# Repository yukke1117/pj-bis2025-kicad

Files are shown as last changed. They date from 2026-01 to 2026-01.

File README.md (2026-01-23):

# af-pj-bis2025

精密アナログ信号処理・データ取得回路のKiCadプロジェクト

## 概要

本プロジェクトは、高精度アナログ信号の取得・調整を目的とした回路基板設計です。24ビットADCを中心に、低ノイズ電源回路とオペアンプによる信号調整回路を組み合わせています。STM32マイコンとの接続を想定した拡張基板として設計されています。

## 主要スペック

- **ADC**: ADS1220IPW (24-bit, TI)
- **オペアンプ**: OPA2380AIDGKR (デュアル), THS4552IPWR (全差動)
- **電圧リファレンス**: REF5050IDR (5V), ADR130BUJZ-REEL7 (精密)
- **電源IC**: MIC5237-5.0YT (5V LDO), UA78L06ACPK (6Vリニアレギュレータ)
- **MOSFET**: ALD114904APAL (低閾値)
- **精密アンプ**: LT1991ACMS-TRPBF
- **コネクタ**: FH28-10S-0.5SH (FPC), SMAコネクタ x2, CN7/CN10 (STM32 Nucleo互換)

## ディレクトリ構成

```
pj-bis2025-kicad/
├── af-pj-bis2025.kicad_pro      # プロジェクトファイル
├── af-pj-bis2025.kicad_sch      # 回路図
├── af-pj-bis2025.kicad_pcb      # PCBレイアウト
├── af-pj-bis2025.kicad_prl      # プロジェクトローカル設定
├── af-pj-bis2025.csv            # 部品表 (BOM)
├── af-pj-bis2025.glb            # 3Dモデル (GLB形式)
├── freerouting.dsn              # 自動配線用ファイル
├── af-pj-bis2025-backups/       # バックアップファイル
├── pj-bis2025.pretty/           # カスタムフットプリントライブラリ
├── pj-bis2025.kicad_sym         # カスタムシンボルライブラリ
├── ultralibrary_zip/            # コンポーネントライブラリ (Ultra Librarian)
├── step/                        # 3Dモデルファイル (STEP形式)
├── stm32/                       # STM32関連サブプロジェクト
│   ├── stm32.kicad_sch          # STM32回路図
│   └── stm32.kicad_pcb          # STM32 PCBレイアウト
├── production/                  # JLCPCB製造用ファイル
│   ├── af-pj-bis2025.zip        # ガーバーファイル一式
│   ├── bom.csv                  # 部品表
│   ├── positions.csv            # 実装位置データ
│   └── netlist.ipc              # IPCネットリスト
└── jlcpcb/                      # JLCPCB製造設定
```

## カスタムライブラリ

### pj-bis2025.pretty (フットプリント)

| フットプリント | 説明 |
|---|---|
| ADS1220-PW16-M | ADC (TSSOP-16) |
| OPA2380-DGK8-M | デュアルオペアンプ (VSSOP-8) |
| THS4552-PW0016A_M | 全差動アンプ (TSSOP-16) |
| REF5050-D8-M | 電圧リファレンス (SOIC-8) |
| LT1991-MSOP-10_MS_LIT-M | 精密アンプ (MSOP-10) |
| MIC5237_5_0YT | 5V LDO (SOT-223) |
| UA78L06ACPK-PK0003A_M | 6Vレギュレータ (SOT-89) |
| ADR130BUJZ_REEL7 | 精密電圧リファレンス (SOT-23) |
| ALD114904APAL-8-PDIP_ALD | MOSFET (PDIP-8) |
| HIROSE_FH28-10S-0.5SH_05_ | FPCコネクタ |
| PTS_647_SN50_SMTR2_LFS | プッシュボタンスイッチ |

### ultralibrary_zip (Ultra Librarian)

Ultra Librarianからダウンロードしたコンポーネントライブラリを含みます。

## 必要環境

- **KiCad 9.0** 以上

## 設計ルール

| 項目 | 値 |
|---|-----|
| 最小トラック幅 | 0.25mm |
| 最小クリアランス | 0.2mm |
| ビア径 | 0.6mm |
| ビアドリル | 0.3mm |
| 最小ホールクリアランス | 0.28mm |
| エッジクリアランス | 0.5mm |

## 製造

製造ファイルは `production/` ディレクトリに出力済みです。JLCPCB向けの以下のファイルが含まれています:

- `af-pj-bis2025.zip` - ガーバーファイル一式
- `bom.csv` - 部品表 (SMT実装用)
- `positions.csv` - 部品配置データ (SMT実装用)

## ライセンス

senserity

## 更新履歴

- 2025-01-23: 基板完成、DRCエラーフリー
- 2025-01-20: GNDベタ配置、アナログ配線完了
- 2025-01-19: アノテーション再定義、フットプリント更新
- 2025-01-18: PCBレイアウト変更
- 2024-11-24: 初期設計

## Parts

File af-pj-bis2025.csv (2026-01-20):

Reference | Qty | Value | DNP | Exclude from BOM | Exclude from Board | Footprint | Datasheet
C1,C2,C12,C16,C20,C23,C27,C30,C34,C35,C36 | 11 | 0.1u_pass |  |  |  | Capacitor_SMD:C_0805_2012Metric_Pad1.18x1.45mm_HandSolder | ~
C3 | 1 | 22u |  |  |  | Capacitor_Tantalum_SMD:CP_EIA-3528-15_AVX-H_HandSolder | ~
C4,C33 | 2 | 1u |  |  |  | Capacitor_SMD:C_0805_2012Metric_Pad1.18x1.45mm_HandSolder | ~
C5 | 1 | TAJR105K016RNJ |  |  |  | Capacitor_SMD:C_0805_2012Metric_Pad1.18x1.45mm_HandSolder | TAJR105K016RNJ
C6,C7 | 2 | 0.1u |  |  |  | Capacitor_SMD:C_0805_2012Metric_Pad1.18x1.45mm_HandSolder | ~
C8,C9 | 2 | 4.7n |  |  |  | Capacitor_SMD:C_0805_2012Metric_Pad1.18x1.45mm_HandSolder | ~
C10,C11,C13,C14 | 4 | 47n |  |  |  | Capacitor_SMD:C_0805_2012Metric_Pad1.18x1.45mm_HandSolder | ~
C15,C21,C22,C28 | 4 | 270p |  |  |  | Capacitor_SMD:C_0805_2012Metric_Pad1.18x1.45mm_HandSolder | ~
C17,C24 | 2 | 470p |  |  |  | Capacitor_SMD:C_0805_2012Metric_Pad1.18x1.45mm_HandSolder | ~
C18,C25 | 2 | 1n |  |  |  | Capacitor_SMD:C_0805_2012Metric_Pad1.18x1.45mm_HandSolder | ~
C19,C26 | 2 | 22n |  |  |  | Capacitor_SMD:C_0805_2012Metric_Pad1.18x1.45mm_HandSolder | ~
C29 | 1 | 0.33u |  |  |  | Capacitor_SMD:C_0805_2012Metric_Pad1.18x1.45mm_HandSolder | ~
C31 | 1 | T491A685K020AT |  |  |  | pj-bis2025:Vref_in_tantal_T491A685K020AT_CAPMP3.4X1.6_1.8N_KEM-M | https://content.kemet.com/datasheets/KEM_T2005_T491.pdf
C32 | 1 | 293D336X9016C2TE3 |  |  |  | pj-bis2025:Vref_out_tantal_293D336X9016C2TE3_CAP_293D-C_VSS | https://www.vishay.com/doc?40002
D1 | 1 | LED |  |  |  | LED_SMD:LED_0805_2012Metric_Pad1.15x1.40mm_HandSolder | ~
J1 | 1 | CN7 |  |  |  | Connector_PinSocket_2.54mm:PinSocket_2x19_P2.54mm_Vertical | ~
J2 | 1 | CN10 |  |  |  | Connector_PinSocket_2.54mm:PinSocket_2x19_P2.54mm_Vertical | ~
J3 | 1 | FH28-10S-0.5SH_05_ |  |  |  | pj-bis2025:HIROSE_FH28-10S-0.5SH_05_
J4 | 1 | Conn_02x05_Odd_Even |  |  |  | Connector_PinSocket_2.54mm:PinSocket_2x05_P2.54mm_Vertical | ~
J5 | 1 | Barrel_Jack_MountingPin |  |  |  | Connector_BarrelJack:BarrelJack_Horizontal | ~
J6,J7 | 2 | Conn_Coaxial |  |  |  | Connector_Coaxial:SMA_Amphenol_901-143_Horizontal | ~
J8,J9,J10,J11 | 4 | Conn_01x02 |  |  |  | Connector_PinHeader_2.54mm:PinHeader_1x02_P2.54mm_Vertical | ~
R1 | 1 | 10k |  |  |  | Resistor_SMD:R_0805_2012Metric_Pad1.20x1.40mm_HandSolder | ~
R2,R3,R4,R5,R33,R34,R35,R36,R37 | 9 | 47 |  |  |  | Resistor_SMD:R_0805_2012Metric_Pad1.20x1.40mm_HandSolder | ~
R6 | 1 | 698 |  |  |  | Resistor_SMD:R_0805_2012Metric_Pad1.20x1.40mm_HandSolder | ~
R7,R8 | 2 | 50k_throughhole |  |  |  | Resistor_SMD:R_0805_2012Metric_Pad1.20x1.40mm_HandSolder | ~
R9,R10 | 2 | 2.4k |  |  |  | Resistor_SMD:R_0805_2012Metric_Pad1.20x1.40mm_HandSolder | ~
R11,R12 | 2 | 100k |  |  |  | Resistor_SMD:R_0805_2012Metric_Pad1.20x1.40mm_HandSolder | ~
R13,R22,R23,R32 | 4 | 1.2k_Rg |  |  |  | Resistor_SMD:R_0805_2012Metric_Pad1.20x1.40mm_HandSolder | ~
R14,R20,R24,R30 | 4 | 1.2k_Ri |  |  |  | Resistor_SMD:R_0805_2012Metric_Pad1.20x1.40mm_HandSolder | ~
R15,R21,R25,R31 | 4 | 330 |  |  |  | Resistor_SMD:R_0805_2012Metric_Pad1.20x1.40mm_HandSolder | ~
R16,R18,R26,R28 | 4 | 5 |  |  |  | Resistor_SMD:R_0805_2012Metric_Pad1.20x1.40mm_HandSolder | ~
R17,R19,R27,R29 | 4 | 10 |  |  |  | Resistor_SMD:R_0805_2012Metric_Pad1.20x1.40mm_HandSolder | ~
SW1,SW2 | 2 | PTS 647 SN50 SMTR2 LFS |  |  |  | pj-bis2025:PTS_647_SN50_SMTR2_LFS_PTS 647 SN50 SMTR2 LFS-M | PTS 647 SN50 SMTR2 LFS
TP1,TP2,TP3,TP4,TP5,TP6,TP7,TP8,TP9,TP10,TP11,TP12,TP13,TP14,TP15,TP16 | 16 | TestPoint |  |  |  | Connector_Pin:Pin_D1.0mm_L10.0mm | ~
U1 | 1 | MIC5237-5.0YT |  |  |  | pj-bis2025:MIC5237_5_0YT | MIC5237-5.0YT
U2 | 1 | ADR130BUJZ-REEL7 |  |  |  | pj-bis2025:ADR130BUJZ_REEL7 | https://www.analog.com/media/en/technical-documentation/data-sheets/ADR130.pdf
U3 | 1 | ALD114904APAL |  |  |  | pj-bis2025:ALD114904APAL-8-PDIP_ALD | ALD114904APAL
U4 | 1 | OPA2380AIDGKR |  |  |  | pj-bis2025:OPA2380-DGK8-M | https://www.ti.com/lit/gpn/opa2380
U5 | 1 | THS4552IPWR |  |  |  | pj-bis2025:THS4552-PW0016A_M | https://www.ti.com/lit/gpn/ths4552
U6 | 1 | REF5050IDR |  |  |  | pj-bis2025:REF5050-D8-M | https://www.ti.com/lit/gpn/ref5050
U7 | 1 | UA78L06ACPK |  |  |  | pj-bis2025:UA78L06ACPK-PK0003A_M | https://www.ti.com/lit/gpn/ua78l
U8 | 1 | ADS1220IPW |  |  |  | pj-bis2025:ADS1220-PW16-M | https://www.ti.com/lit/gpn/ads1220

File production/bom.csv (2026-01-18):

Designator | Footprint | Quantity | Value | LCSC Part #
C1 | 0805 | 1 | TAJR105K016RNJ
C10, C14, C18, C20, C24, C27, C31, C32, C33, C34, C6, C8 | 0805 | 12 | 0.1u_pass
C11, C12, C7, C9 | 0805 | 4 | 47n
C13, C23, C26, C35 | 0805 | 4 | 270p
C15, C28 | 0805 | 2 | 470p
C16, C29 | 0805 | 2 | 1n
C17, C30 | 0805 | 2 | 22n
C19 | 0805 | 1 | 0.33u
C2 | CP_EIA-3528-15_AVX-H_HandSolder | 1 | C_Vin
C21 | Vref_in_tantal_T491A685K020AT_CAPMP3.4X1.6_1.8N_KEM-M | 1 | T491A685K020AT
C22 | Vref_out_tantal_293D336X9016C2TE3_CAP_293D-C_VSS | 1 | 293D336X9016C2TE3
C25 | 0805 | 1 | 1u
C3 | 0805 | 1 | 1µF
C4, C5 | 0805 | 2 | 4.7n
D1 | 0805 | 1 | LED
J1 | BarrelJack_Horizontal | 1 | Barrel_Jack_MountingPin
J10, J11, J8, J9 | PinHeader_1x02_P2.54mm_Vertical | 4 | Conn_01x02
J12 | HIROSE_FH28-10S-0.5SH_05_ | 1 | FH28-10S-0.5SH_05_
J2 | PinSocket_2x19_P2.54mm_Vertical | 1 | CN7
J3, J4 | SMA_Amphenol_901-143_Horizontal | 2 | Conn_Coaxial
J5 | PinSocket_2x19_P2.54mm_Vertical | 1 | CN10
J6 | JST_XH_B10B-XH-A_1x10_P2.50mm_Vertical | 1 | Conn_01x10
J7 | PinHeader_1x06_P2.54mm_Vertical | 1 | Conn_01x06
R1, R2 | 0805 | 2 | 50k_throughhole
R10, R12, R25, R27 | 0805 | 4 | 5
R11, R13, R26, R28 | 0805 | 4 | 10
R14, R21, R29, R8 | 0805 | 4 | 1.2k_Ri
R15, R22, R30, R9 | 0805 | 4 | 330
R16, R17, R31, R7 | 0805 | 4 | 1.2k_Rg
R18, R19, R20, R23, R24, R32, R33, R34, R35 | 0805 | 9 | 47
R3, R4 | 0805 | 2 | 2.4k
R36 | 0805 | 1 | 698
R37 | 0805 | 1 | 10k
R5, R6 | 0805 | 2 | 100k
SW1, SW2 | PTS_647_SN50_SMTR2_LFS_PTS 647 SN50 SMTR2 LFS-M | 2 | PTS 647 SN50 SMTR2 LFS
TP1, TP10, TP11, TP12, TP13, TP14, TP15, TP16, TP2, TP3, TP4, TP5, TP7, TP8, TP9 | Pin_D1.0mm_L10.0mm | 15 | TestPoint
U1 | MIC5237_5_0YT | 1 | MIC5237-5.0YT
U2 | ALD114904APAL-8-PDIP_ALD | 1 | ALD114904APAL
U3 | OPA2380-DGK8-M | 1 | OPA2380AIDGKR
U4 | THS4552-PW0016A_M | 1 | THS4552IPWR
U5 | REF5050-D8-M | 1 | REF5050IDR
U6 | LT1991-MSOP-10_MS_LIT-M | 1 | LT1991ACMS-TRPBF
U7 | UA78L06ACPK-PK0003A_M | 1 | UA78L06ACPK
U8 | ADS1220-PW16-M | 1 | ADS1220IPW

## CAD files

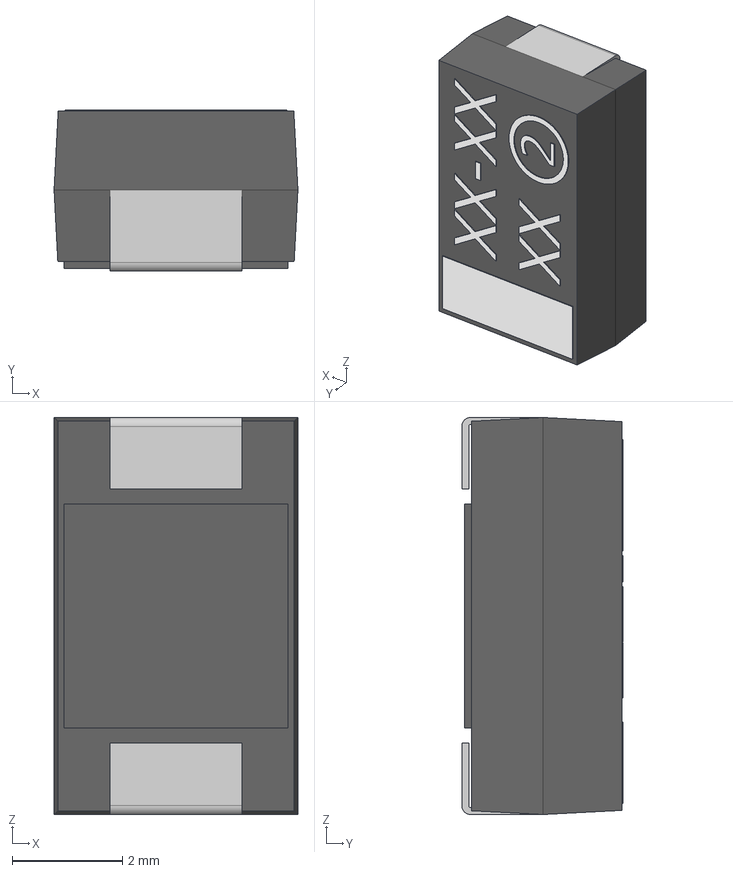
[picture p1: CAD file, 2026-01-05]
step/293D336X9016C2TE3_3dmodels/D-CASE.stp
4.42 x 2.92 x 7.19 mm

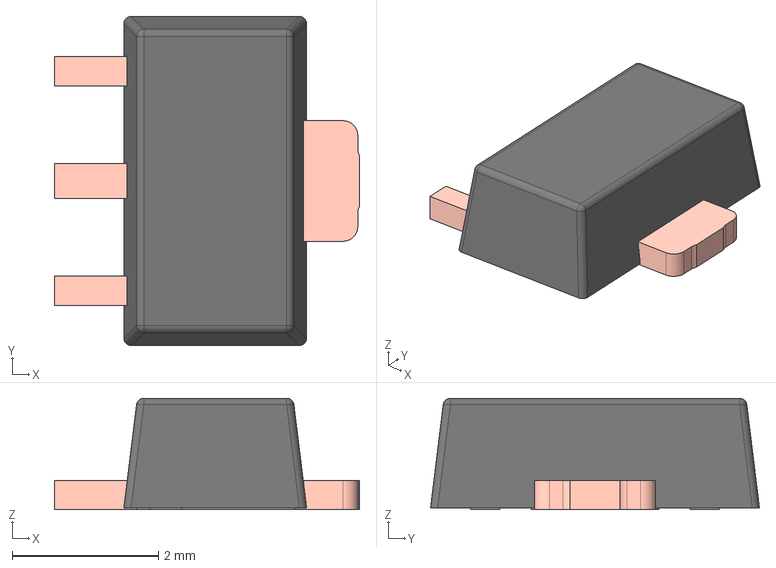
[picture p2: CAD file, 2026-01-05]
step/UA78L06ACPK.stp
4.17 x 4.50 x 1.52 mm
FRAME
MOLD

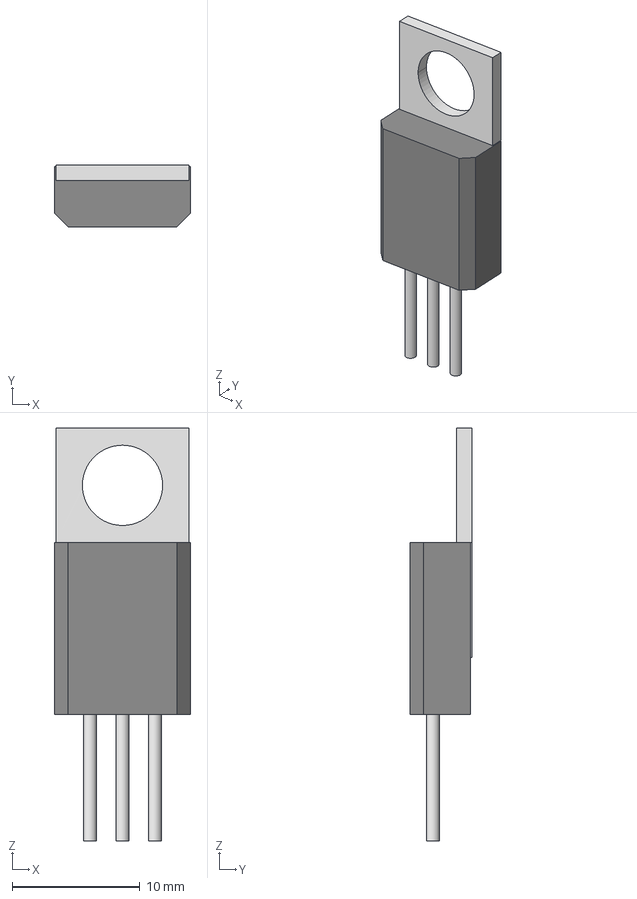
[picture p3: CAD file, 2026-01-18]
ultralibrary_zip/MIC5237_5_0YT/TO-220-3_MCL.step
10.7 x 4.83 x 32.4 mm

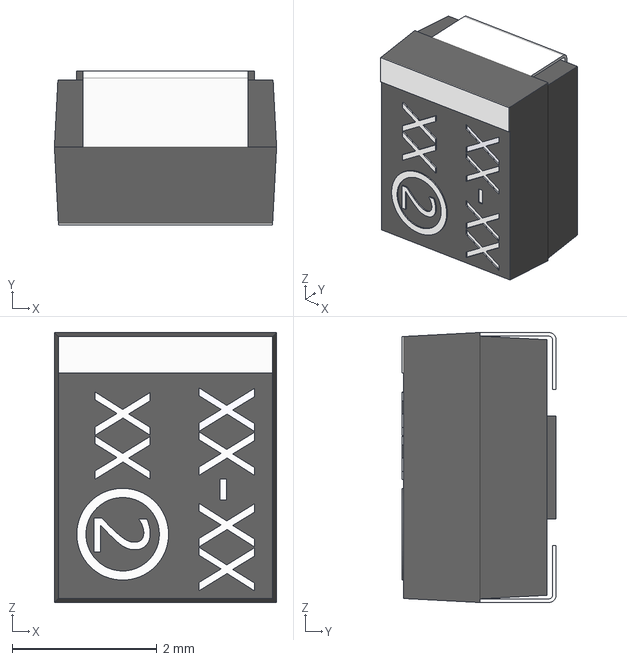
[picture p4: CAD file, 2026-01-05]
step/293D336X9016C2TE3_3dmodels/B-CASE.stp
3.07 x 2.13 x 3.73 mm

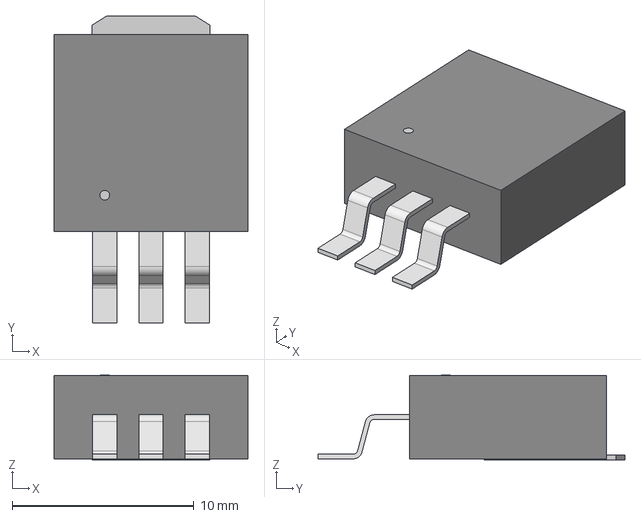
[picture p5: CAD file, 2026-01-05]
step/MIC5237_5_0YU.step
10.7 x 16.9 x 4.65 mm

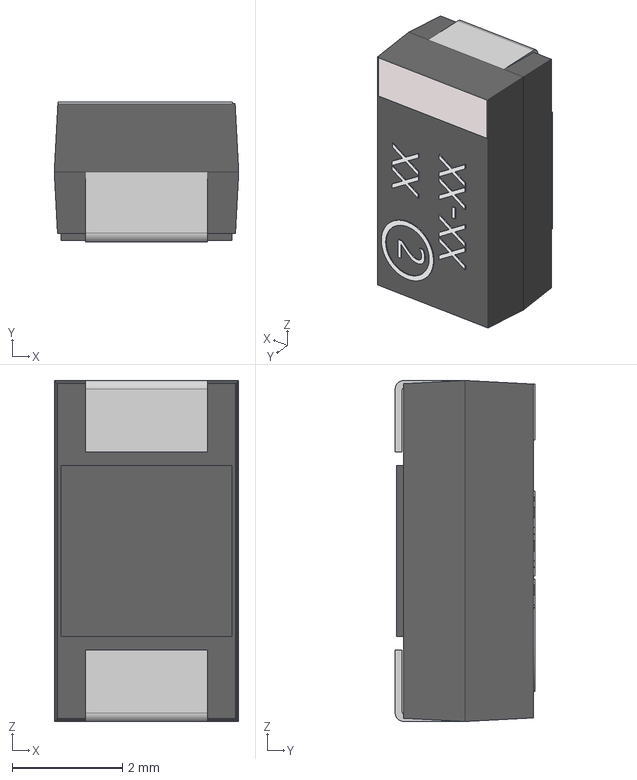
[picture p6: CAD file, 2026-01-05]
step/293D336X9016C2TE3_3dmodels/C-CASE.stp
3.35 x 2.54 x 6.20 mm

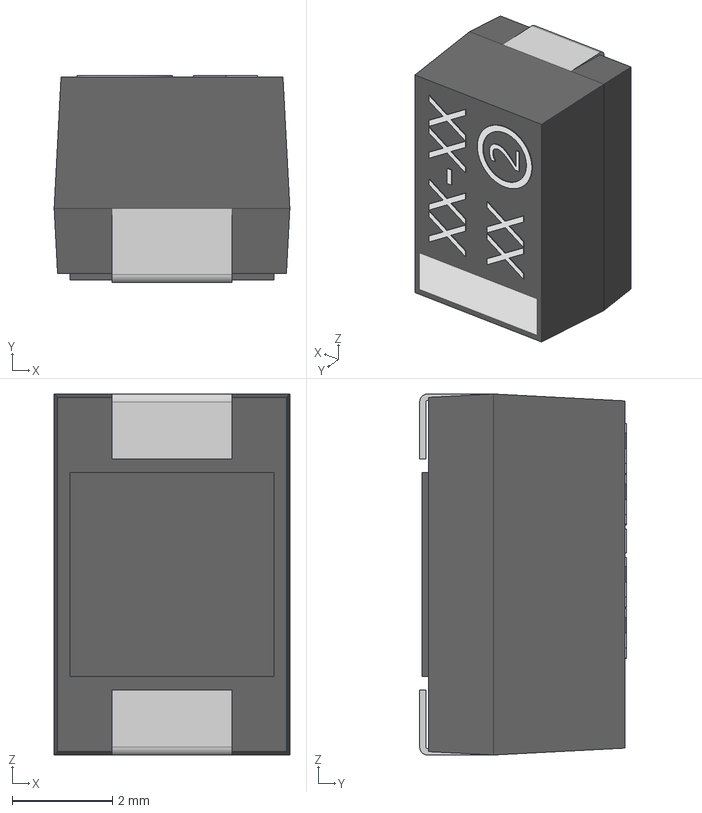
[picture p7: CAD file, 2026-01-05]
step/293D336X9016C2TE3_3dmodels/E-CASE.stp
4.69 x 4.11 x 7.19 mm

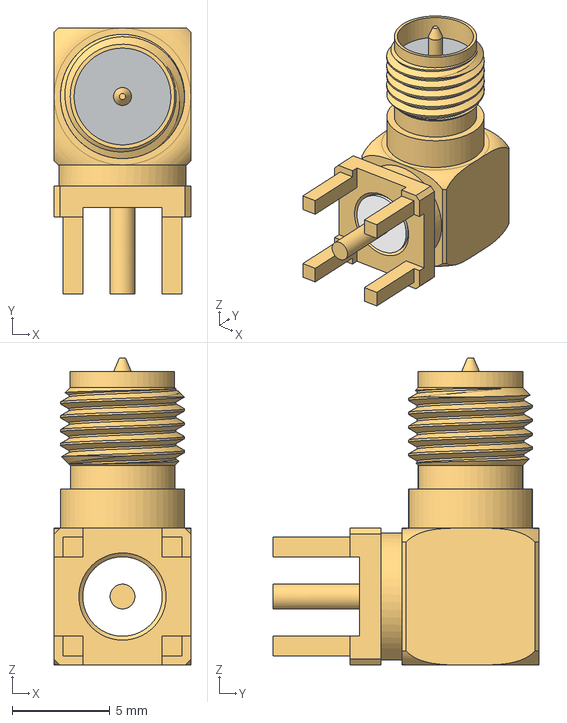
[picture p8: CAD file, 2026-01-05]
step/SMA_connector.stp
7.00 x 13.6 x 15.7 mm

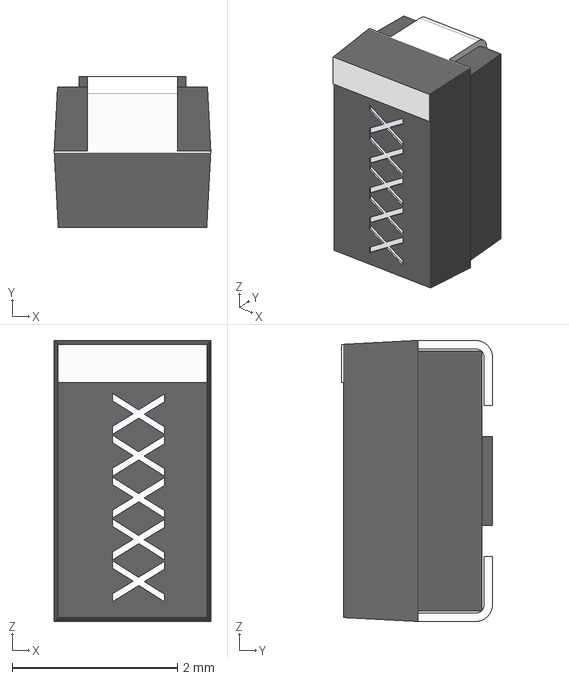
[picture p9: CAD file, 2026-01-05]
step/293D336X9016C2TE3_3dmodels/A-CASE.stp
1.90 x 1.83 x 3.40 mm

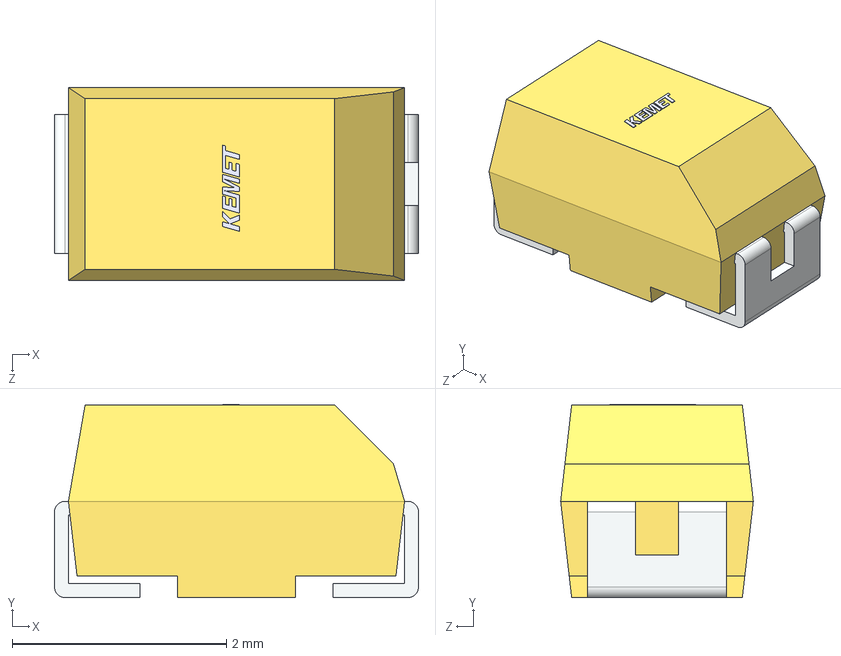
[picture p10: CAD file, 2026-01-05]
step/T491A685K020AT.step
3.40 x 1.81 x 1.80 mm

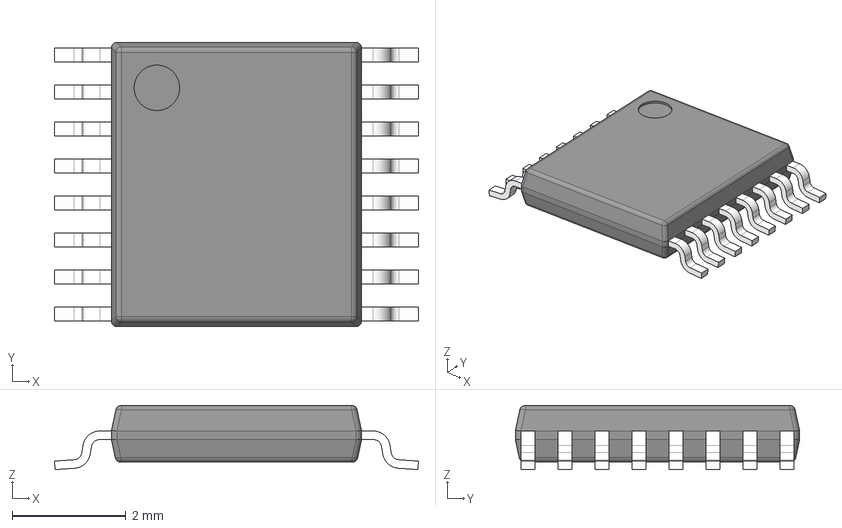
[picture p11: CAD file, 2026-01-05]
step/ADS1220IPW.stp
6.40 x 5.00 x 1.13 mm
BODY-TSSOP
LEAD-TSSOP x 16
PIN1

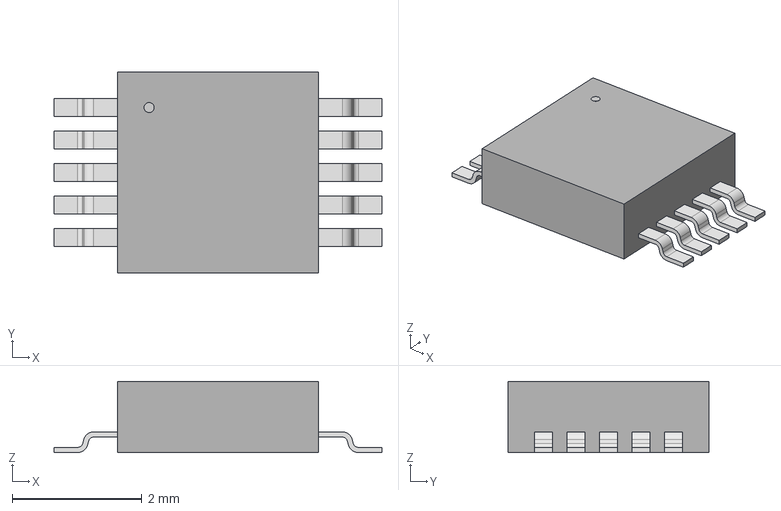
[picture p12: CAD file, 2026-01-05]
step/LT1991ACMS_TRPBF.step
5.05 x 3.10 x 1.09 mm

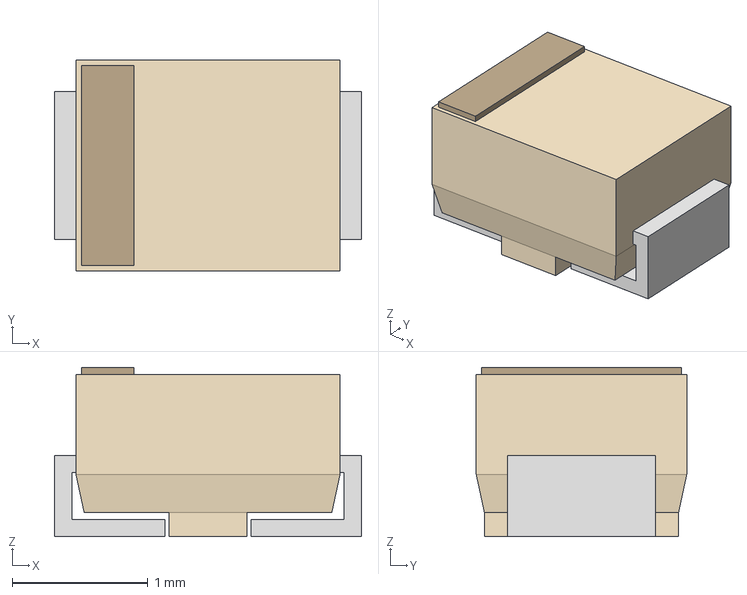
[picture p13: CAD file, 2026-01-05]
step/TAJR105K016RNJ.step
2.26 x 1.55 x 1.25 mm

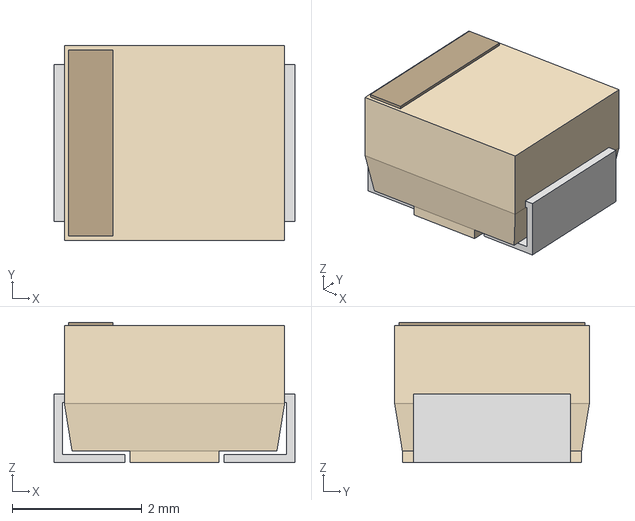
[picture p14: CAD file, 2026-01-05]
step/TCJB105M050R0300.step
3.71 x 3.00 x 2.16 mm

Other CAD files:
step/OPA2380AIDGKR.stp
step/REF5050IDR.stp
step/ALD114904APAL.step

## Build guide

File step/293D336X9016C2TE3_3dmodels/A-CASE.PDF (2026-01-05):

THE INFORMATION AND/OR MATERIAL IN THIS DOCUMENT IS THE PROPERTY OF AND RESTRICTED INFORMATION AND/OR MATERIAL OF THE AUTHOR. THIS INFORMATION MAY NOT BE
USED, REPRODUCED, PUBLISHED OR DISCLOSED TO OTHERS WITHOUT WRITTEN AUTHORIZATION. IT IS TO BE USED ONLY FOR MANUFACTURING ITEMS SPECIFIED WITHIN THE DOCUMENT.

# 293D A-CASE

TITLE PART NO | 293D A-CASE REVISION DESIGNER | AMitiagin ENGINEER NOTES | v1.0

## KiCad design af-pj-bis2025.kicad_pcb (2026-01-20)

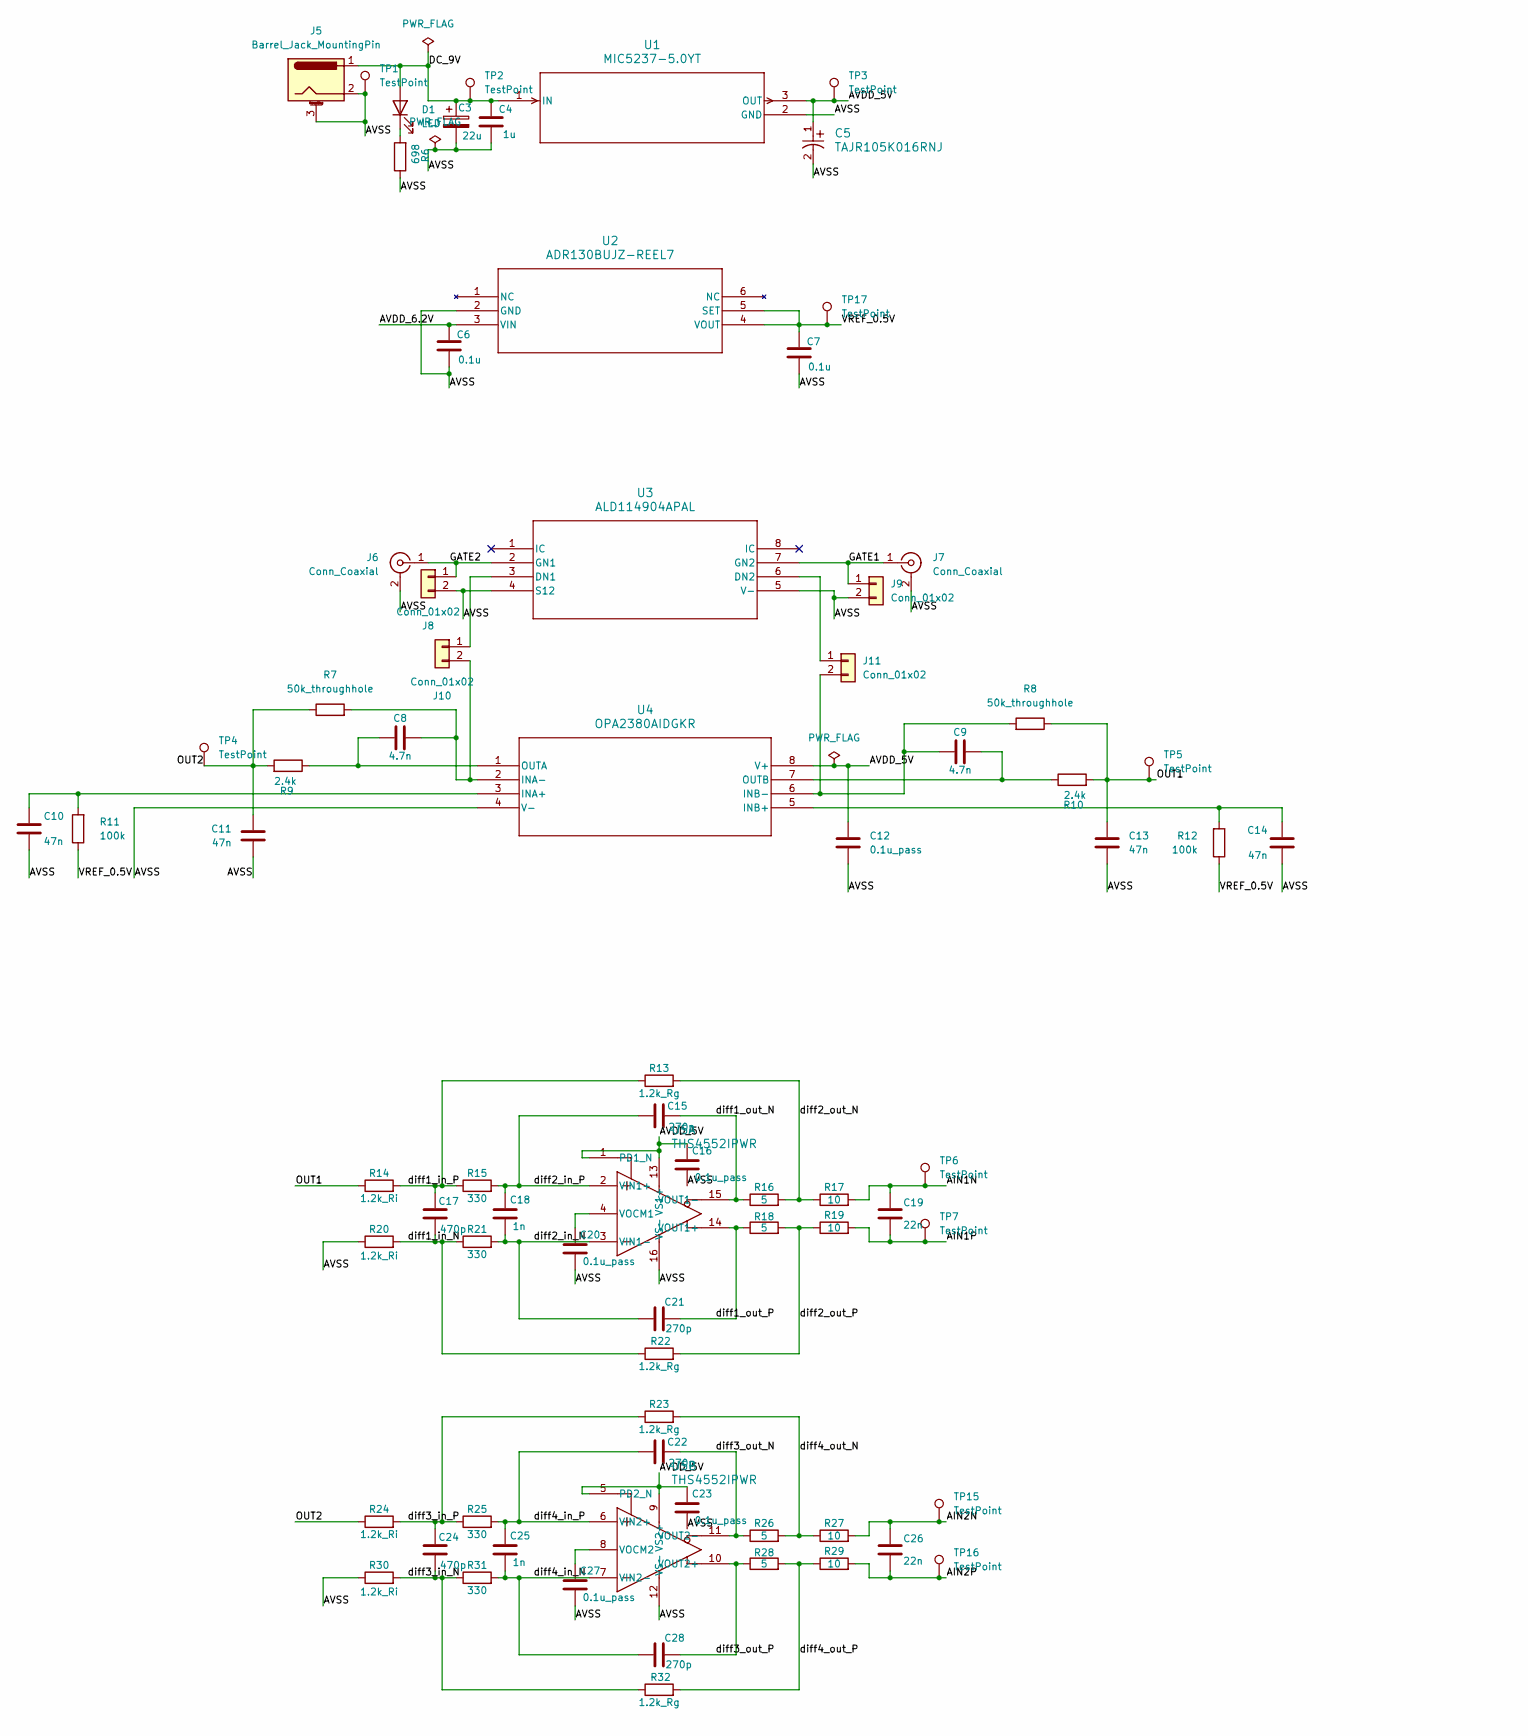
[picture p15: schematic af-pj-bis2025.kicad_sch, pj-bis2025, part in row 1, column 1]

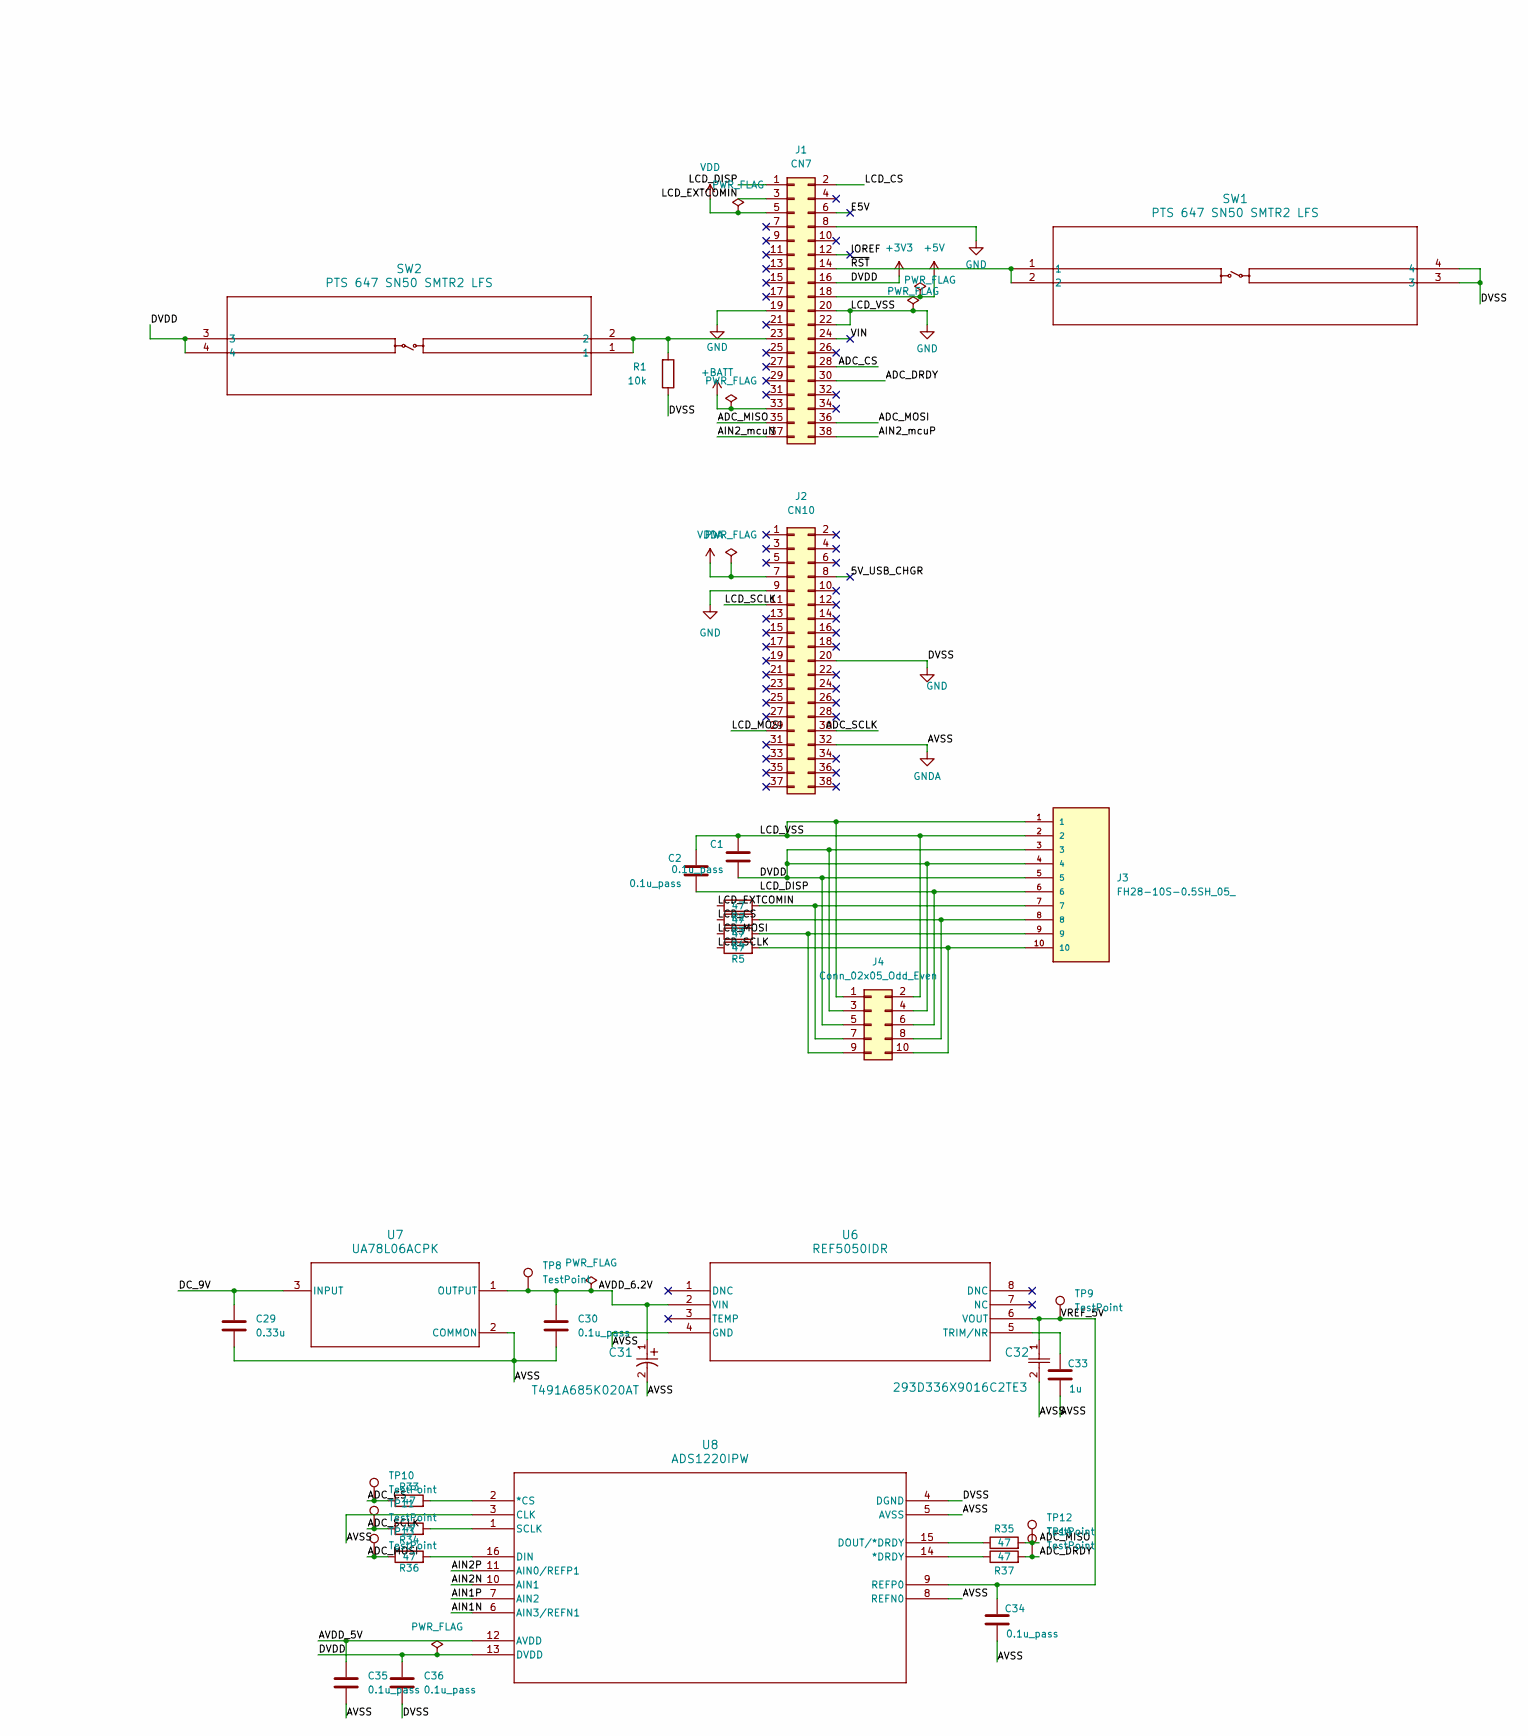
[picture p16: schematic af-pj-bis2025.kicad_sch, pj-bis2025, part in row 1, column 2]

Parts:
C1, C2, C12, C16, C20, C23, C27, C30, C34, C35, C36: 0.1u_pass; C_0805_2012Metric_Pad1.18x1.45mm_HandSolder
C3: 22u; CP_EIA-3528-15_AVX-H_HandSolder
C4, C33: 1u; C_0805_2012Metric_Pad1.18x1.45mm_HandSolder
C5: TAJR105K016RNJ; C_0805_2012Metric_Pad1.18x1.45mm_HandSolder
C6, C7: 0.1u; C_0805_2012Metric_Pad1.18x1.45mm_HandSolder
C8, C9: 4.7n; C_0805_2012Metric_Pad1.18x1.45mm_HandSolder
C10, C11, C13, C14: 47n; C_0805_2012Metric_Pad1.18x1.45mm_HandSolder
C15, C21, C22, C28: 270p; C_0805_2012Metric_Pad1.18x1.45mm_HandSolder
C17, C24: 470p; C_0805_2012Metric_Pad1.18x1.45mm_HandSolder
C18, C25: 1n; C_0805_2012Metric_Pad1.18x1.45mm_HandSolder
C19, C26: 22n; C_0805_2012Metric_Pad1.18x1.45mm_HandSolder
C29: 0.33u; C_0805_2012Metric_Pad1.18x1.45mm_HandSolder
C31: T491A685K020AT; Vref_in_tantal_T491A685K020AT_CAPMP3.4X1.6_1.8N_KEM-M
C32: 293D336X9016C2TE3; Vref_out_tantal_293D336X9016C2TE3_CAP_293D-C_VSS
D1: LED; LED_0805_2012Metric_Pad1.15x1.40mm_HandSolder
J1: CN7; PinSocket_2x19_P2.54mm_Vertical
J2: CN10; PinSocket_2x19_P2.54mm_Vertical
J3: FH28-10S-0.5SH_05_; HIROSE_FH28-10S-0.5SH_05_; PARTREV 13.09.20
J4: Conn_02x05_Odd_Even; PinSocket_2x05_P2.54mm_Vertical
J5: Barrel_Jack_MountingPin; BarrelJack_Horizontal
J6, J7: Conn_Coaxial; SMA_Amphenol_901-143_Horizontal
J8, J9, J10, J11: Conn_01x02; PinHeader_1x02_P2.54mm_Vertical
R1: 10k; R_0805_2012Metric_Pad1.20x1.40mm_HandSolder
R2, R3, R4, R5, R33, R34, R35, R36, R37: 47; R_0805_2012Metric_Pad1.20x1.40mm_HandSolder
R6: 698; R_0805_2012Metric_Pad1.20x1.40mm_HandSolder
R7, R8: 50k_throughhole; R_0805_2012Metric_Pad1.20x1.40mm_HandSolder
R9, R10: 2.4k; R_0805_2012Metric_Pad1.20x1.40mm_HandSolder
R11, R12: 100k; R_0805_2012Metric_Pad1.20x1.40mm_HandSolder
R13, R22, R23, R32: 1.2k_Rg; R_0805_2012Metric_Pad1.20x1.40mm_HandSolder
R14, R20, R24, R30: 1.2k_Ri; R_0805_2012Metric_Pad1.20x1.40mm_HandSolder
R15, R21, R25, R31: 330; R_0805_2012Metric_Pad1.20x1.40mm_HandSolder
R16, R18, R26, R28: 5; R_0805_2012Metric_Pad1.20x1.40mm_HandSolder
R17, R19, R27, R29: 10; R_0805_2012Metric_Pad1.20x1.40mm_HandSolder
SW1, SW2: PTS 647 SN50 SMTR2 LFS; PTS_647_SN50_SMTR2_LFS_PTS 647 SN50 SMTR2 LFS-M
TP1, TP2, TP3, TP4, TP5, TP6, TP7, TP8, TP9, TP10, TP11, TP12, TP13, TP14, TP15, TP16, TP17: TestPoint; Pin_D1.0mm_L10.0mm
U1: MIC5237-5.0YT; MIC5237_5_0YT
U2: ADR130BUJZ-REEL7; ADR130BUJZ_REEL7
U3: ALD114904APAL; ALD114904APAL-8-PDIP_ALD
U4: OPA2380AIDGKR; OPA2380-DGK8-M
U5: THS4552IPWR; THS4552-PW0016A_M
U6: REF5050IDR; REF5050-D8-M
U7: UA78L06ACPK; UA78L06ACPK-PK0003A_M
U8: ADS1220IPW; ADS1220-PW16-M

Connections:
+3V3: C1.1, C36.1, J1.16, J3.3, J3.4, J3.5, J4.3, J4.4, J4.5, SW2.3, SW2.4, U8.13 (DVDD)
+5V: J1.18
+BATT: J1.33
/5V_USB_CHGR: J2.8
/ADC_CS: J1.28, R33.1, TP10.1
/ADC_DRDY: J1.30, R37.2, TP14.1
/ADC_MISO: J1.35, R35.2, TP12.1
/ADC_MOSI: J1.36, R36.1, TP13.1
/ADC_SCLK: J2.30, R34.1, TP11.1
/AIN1N: C19.2, R17.2, TP6.1, U8.6 (AIN3/REFN1)
/AIN1P: C19.1, R19.2, TP7.1, U8.7 (AIN2)
/AIN2N: C26.2, R27.2, TP15.1, U8.10 (AIN1)
/AIN2P: C26.1, R29.2, TP16.1, U8.11 (AIN0/REFP1)
/AIN2_mcuN: J1.37
/AIN2_mcuP: J1.38
/AVDD_5V: C5.1, C12.2, C16.2, C23.2, C35.1, TP3.1, U1.3 (OUT), U4.8 (V+), U5.1 (PD1_N), U5.5 (PD2_N), U5.9 (VS2+), U5.13 (VS1+), U8.12 (AVDD)
/AVDD_6.2V: C6.1, C30.1, C31.1, TP8.1, U2.3 (VIN), U6.2 (VIN), U7.1 (OUTPUT)
/DC_9V: C3.1, C4.1, C29.1, D1.2 (A), J5.1, TP2.1, U1.1 (IN), U7.3 (INPUT)
/E5V: J1.6
/GATE1: J7.1 (In), J9.1, U3.7 (GN2)
/GATE2: J6.1 (In), J8.1, U3.2 (GN1)
/IOREF: J1.12
/LCD_CS: J1.2, R3.1
/LCD_DISP: C2.1, J1.1, J3.6, J4.6
/LCD_EXTCOMIN: J1.3, R2.1
/LCD_MOSI: J2.29, R4.1
/LCD_SCLK: J2.11, R5.1
/OUT1: C13.2, R8.1, R10.2, R14.1, TP5.1
/OUT2: C11.2, R7.1, R9.2, R24.1, TP4.1
/VIN: J1.24
/VREF_0.5V: C7.1, R11.1, R12.1, TP17.1, U2.4 (VOUT), U2.5 (SET)
/VREF_5V: C32.1, C34.1, TP9.1, U6.6 (VOUT), U8.9 (REFP0)
/diff1_in_N: C17.1, R20.2, R21.1, R22.1
/diff1_in_P: C17.2, R13.1, R14.2, R15.1
/diff1_out_N: C15.1, R16.1, U5.15 (VOUT1-)
/diff1_out_P: C21.1, R18.1, U5.14 (VOUT1+)
/diff2_in_N: C18.1, C21.2, R21.2, U5.3 (VIN1-)
/diff2_in_P: C15.2, C18.2, R15.2, U5.2 (VIN1+)
/diff2_out_N: R13.2, R16.2, R17.1
/diff2_out_P: R18.2, R19.1, R22.2
/diff3_in_N: C24.1, R30.2, R31.1, R32.1
/diff3_in_P: C24.2, R23.1, R24.2, R25.1
/diff3_out_N: C22.1, R26.1, U5.11 (VOUT2-)
/diff3_out_P: C28.1, R28.1, U5.10 (VOUT2+)
/diff4_in_N: C25.1, C28.2, R31.2, U5.7 (VIN2-)
/diff4_in_P: C22.2, C25.2, R25.2, U5.6 (VIN2+)
/diff4_out_N: R23.2, R26.2, R27.1
/diff4_out_P: R28.2, R29.1, R32.2
/~RST: J1.14, SW1.1, SW1.2
GND: C1.2, C2.2, C36.2, J1.8, J1.19, J1.20, J1.22, J2.9, J2.20, J3.1, J3.2, J4.1, J4.2, R1.1, SW1.3, SW1.4, U8.4 (DGND)
GNDA: C3.2, C4.2, C5.2, C6.2, C7.2, C10.1, C11.1, C12.1, C13.1, C14.1, C16.1, C20.1, C23.1, C27.1, C29.2, C30.2, C31.2, C32.2, C33.2, C34.2, C35.2, J2.32, J5.2, J5.3 (MountPin), J6.2 (Ext), J7.2 (Ext), J8.2, J9.2, R6.1, R20.1, R30.1, TP1.1, U1.2 (GND), U2.2 (GND), U3.4 (S12), U3.5 (V-), U4.4 (V-), U5.12 (VS-), U5.16 (VS-), U6.4 (GND), U7.2 (COMMON), U8.3 (CLK), U8.5 (AVSS), U8.8 (REFN0)
unnamed: D1.1 (K), R6.2
unnamed: J1.23, R1.2, SW2.1, SW2.2
unnamed: J3.7, J4.7, R2.2
unnamed: J3.8, J4.8, R3.2
unnamed: J3.9, J4.9, R4.2
unnamed: J3.10, J4.10, R5.2
unnamed: J10.1, U3.3 (DN1)
unnamed: C8.2, J10.2, R7.2, U4.2 (INA-)
unnamed: J11.1, U3.6 (DN2)
unnamed: C9.2, J11.2, R8.2, U4.6 (INB-)
unnamed: C10.2, R11.2, U4.3 (INA+)
unnamed: C14.2, R12.2, U4.5 (INB+)
unnamed: C8.1, R9.1, U4.1 (OUTA)
unnamed: C9.1, R10.1, U4.7 (OUTB)
unnamed: C20.2, U5.4 (VOCM1)
unnamed: C27.2, U5.8 (VOCM2)
unnamed: C33.1, U6.5 (TRIM/NR)
unnamed: R33.2, U8.2 (*CS)
unnamed: R37.1, U8.14 (*DRDY)
unnamed: R36.2, U8.16 (DIN)
unnamed: R35.1, U8.15 (DOUT/*DRDY)
unnamed: R34.2, U8.1 (SCLK)
VDD: J1.5
VDDA: J2.7

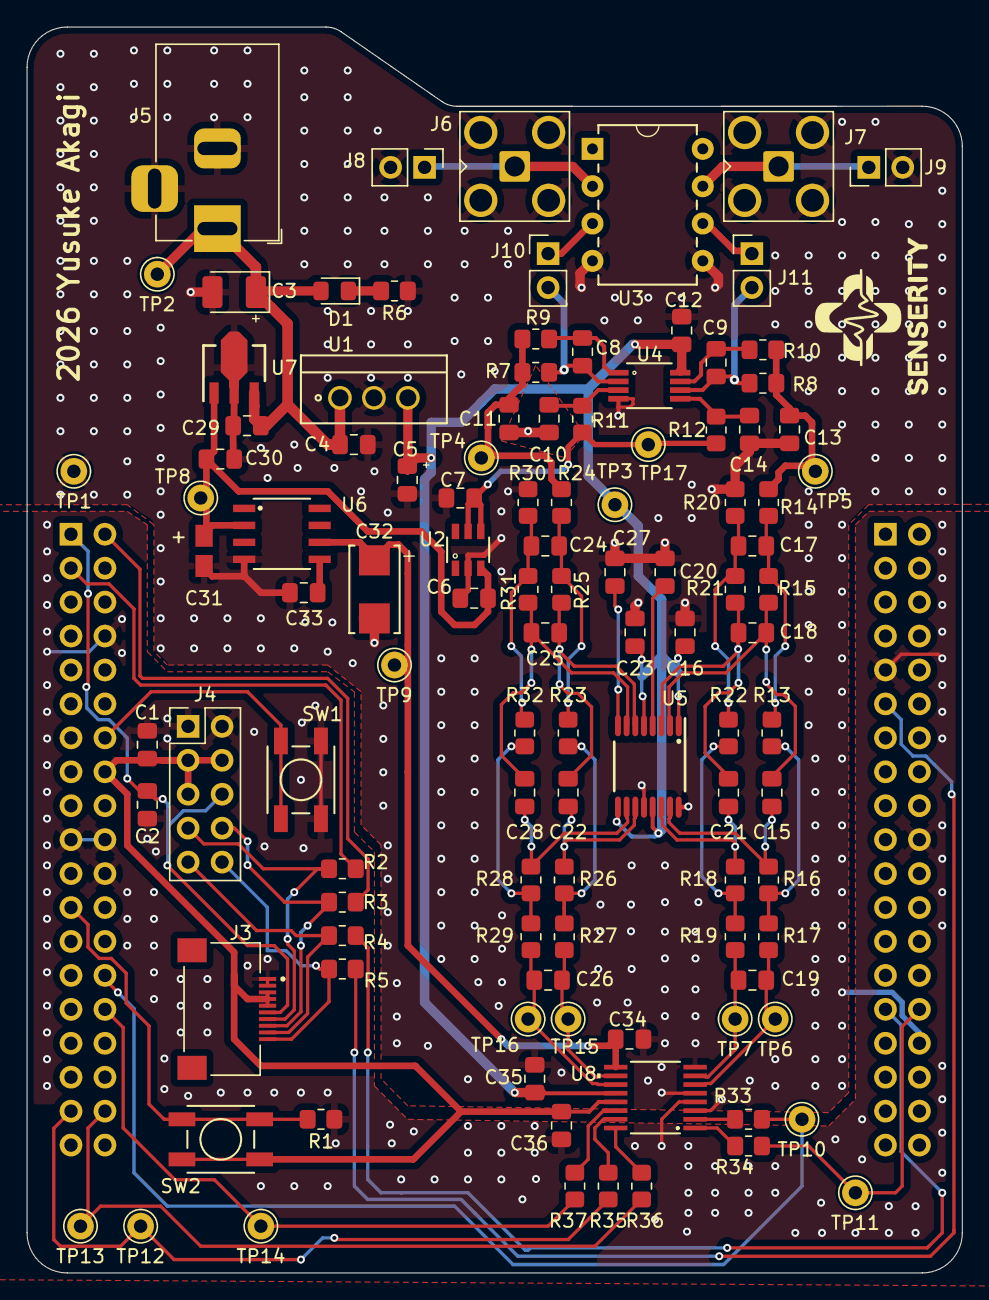
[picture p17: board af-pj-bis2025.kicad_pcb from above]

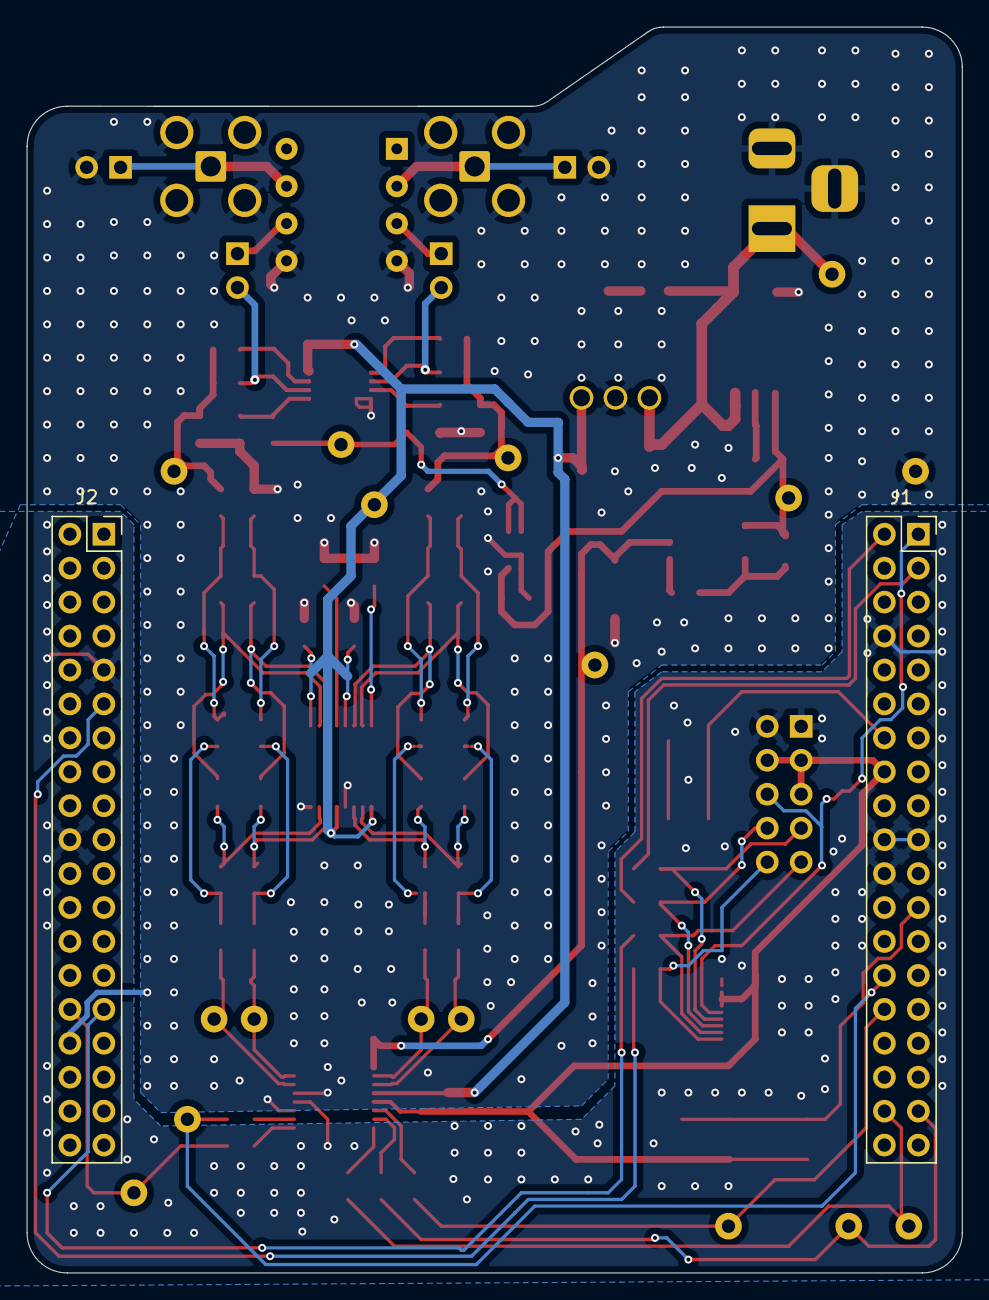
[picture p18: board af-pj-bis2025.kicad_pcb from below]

Board: 2 copper layers, 70.0 x 93.2 mm, 112 parts (2 on the bottom side), 65 nets.

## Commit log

2025-12-22 inititl commit
    [af-pj-bis2025.kicad_pcb, af-pj-bis2025.kicad_sch]
2025-12-29 ADC追加
    [af-pj-bis2025.kicad_sch]
2025-12-30 ERCを解消した1
    [af-pj-bis2025.kicad_sch]
2025-12-30 ERCエラー修正2
    [af-pj-bis2025.kicad_sch]
2025-12-30 パスコンを追加
    [af-pj-bis2025.kicad_sch]
2025-12-30 フットプリントの割り当て
2026-01-02 Uのフットプリント割り当て完了
    [af-pj-bis2025.kicad_sch]
2026-01-02 アノテーション
    [af-pj-bis2025.kicad_sch]
2026-01-02 タンタルキャパシタ置き換え、フットプリント割り当て
    [af-pj-bis2025.kicad_sch]
2026-01-02 キャパシタをタンタルキャパシタに変更した
    [af-pj-bis2025.kicad_sch]
2026-01-02 フットプリント割り当て完了
    [af-pj-bis2025.kicad_sch]
2026-01-02 drc設定と、pcbの更新完了
    [af-pj-bis2025.kicad_pcb]
2026-01-03 差動増幅回路のレイアウト完了
    [af-pj-bis2025.kicad_pcb, stm32.kicad_pcb, stm32.kicad_sch]
2026-01-03 AVSS接続完了
    [af-pj-bis2025.kicad_pcb, af-pj-bis2025.kicad_sch]
2026-01-03 AVDD-5Vを配線
    [af-pj-bis2025.kicad_pcb]
2026-01-03 LCDの配線完了
    [af-pj-bis2025.kicad_pcb, af-pj-bis2025.kicad_sch]
2026-01-03 ADCのディジタル配線完了
    [af-pj-bis2025.kicad_pcb, af-pj-bis2025.kicad_sch]
2026-01-03 EdgeCutsを調整した
    [af-pj-bis2025.kicad_pcb, af-pj-bis2025.kicad_sch, freerouting.dsn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]
2026-01-03 DRC,LVSクリアとテストピン、デバック用ピン追加
    [af-pj-bis2025.kicad_pcb, af-pj-bis2025.kicad_sch, freerouting.dsn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]
2026-01-05 回路が完成した
    [A-CASE.stp, ADS1220IPW.stp, ALD114904APAL.step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]
2026-01-18 change PCB layout
    [af-pj-bis2025.kicad_pcb, af-pj-bis2025.kicad_sch]
2026-01-18 LCDのコネクタ変更(schematic)
    [af-pj-bis2025.kicad_sch]
2026-01-18 ADCのコネクタ削除(Schematic)
    [af-pj-bis2025.kicad_sch]
2026-01-18 アノテーションを再定義
    [af-pj-bis2025.kicad_sch]
2026-01-18 0.5Vrefのフットプリントを更新
    [af-pj-bis2025.kicad_pcb, af-pj-bis2025.kicad_sch]
2026-01-18 アナログ配線完了
    [af-pj-bis2025.csv, af-pj-bis2025.kicad_pcb, af-pj-bis2025.kicad_sch]
2026-01-18 GND以外終わり
    [af-pj-bis2025.kicad_pcb, af-pj-bis2025.kicad_sch]
2026-01-18 GNDベタを配置
    [af-pj-bis2025.kicad_pcb]
2026-01-18 DRCエラーフリー
    [af-pj-bis2025.kicad_pcb]
2026-01-18 基板完成
    [af-pj-bis2025.kicad_pcb, af-pj-bis2025.kicad_sch]
